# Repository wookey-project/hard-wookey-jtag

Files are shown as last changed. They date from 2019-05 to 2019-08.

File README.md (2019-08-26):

# WooKey JTAG Flasher PCB

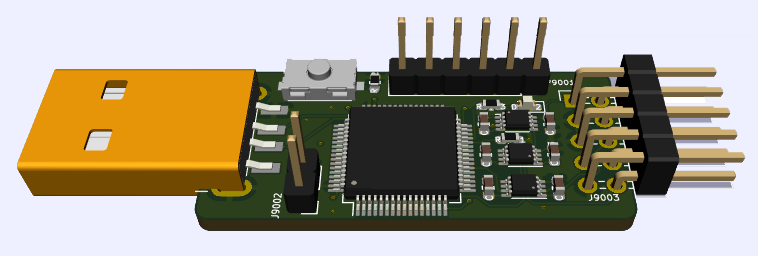
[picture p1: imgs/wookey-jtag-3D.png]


## Introduction

Wookey | https://wookey-project.github.io/
Copyright 2018 ANSSI

Authors: The Wookey project Team <wookey@ssi.gouv.fr>

The Wookey from [ANSSI](https://www.ssi.gouv.fr) is an open source
hardware design, implementing an Encrypted Flash Drives.

This repository is aimed towards developers.

### Revision information

This directory contains the hardware design for the Wookey board, first public version (Wookey V2).

### PCB editing tools

All PCB files (schematic and PCB layout) have been designed using the KiCad EDA.
This Cross Platform and Open Source Electronics Design Automation Suite can be downloaded
on http://kicad-pcb.org/.

## Production files generation 101

### Configure the project

KiCad binaries location may change regarding your operating system.
This is why you have to set your environment.
This is done by sourcing the `setenv.sh` script. This script exports
all paths that are required in order to automaticaly generate the production files.

Most of the time, the paths proposed in this script are not the one you use in your specific installation.
The `setenv.sh` script support easy variables overloading by including a `setenv.local.sh` script file if this file exists in the same directory.
If you need to overload some of the variables of the `setenv.sh` script, just add them to your own `setenv.local.sh` file.
Here is an example to define KiCad environement path on Apple Mac OS.

```
  $ echo "export PYTHON_BIN_PATH = /Applications/KiCad/kicad.app/Contents/Frameworks/Python.framework/Versions/2.7/bin/python" > setenv.local.sh
  $ source setenv.sh
  Loading local SDK settings...
  =========================================================
  === Kicad environment configuration
  =========================================================
  PYTHON_BIN_PATH   = /Applications/KiCad/kicad.app/Contents/Frameworks/Python.framework/Versions/2.7/bin/python
  PYTHON_PATH     = /Applications/Kicad/kicad.app/Contents/Frameworks/python/site-packages
  BOM_GEN_PATH = /Applications/Kicad/kicad.app/Contents/SharedSupport/plugins/bom2grouped_csv.xsl
  TOOLS_PATH = ../../../tools
  =========================================================
```

The production files can be generated using the following command.

```
$ make
```

This will generate the production files in a new sub directory.
The directory name may differ according the project your are working with.

## PCB Pinout

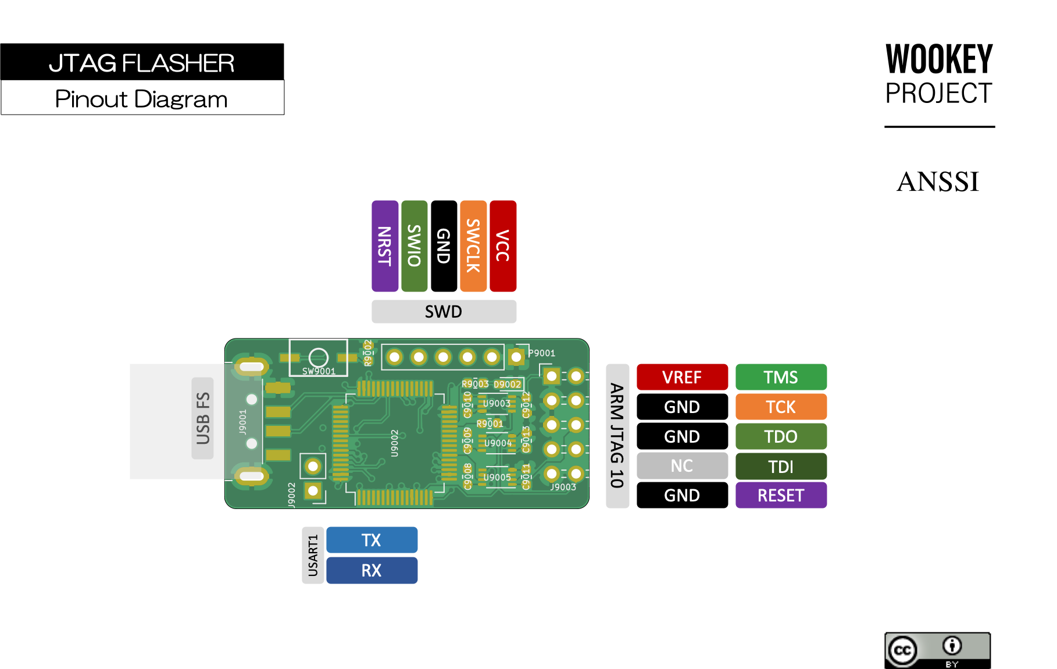
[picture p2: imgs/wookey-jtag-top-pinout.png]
Pinout


## PCB Layers

### PCB TOP layer

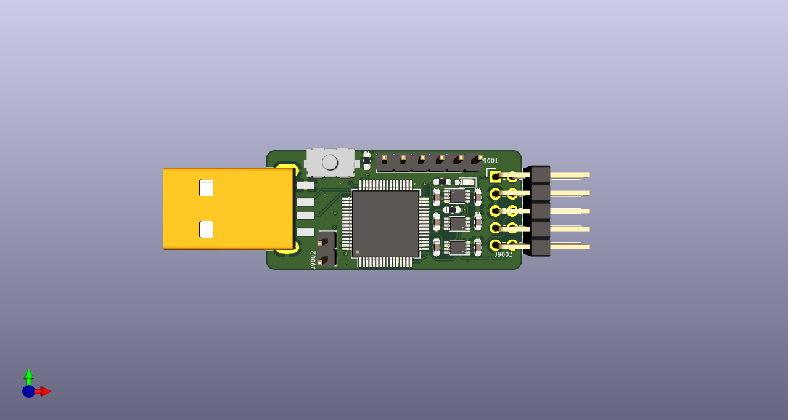
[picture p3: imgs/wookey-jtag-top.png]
TOP


### PCB BOTTOM layer

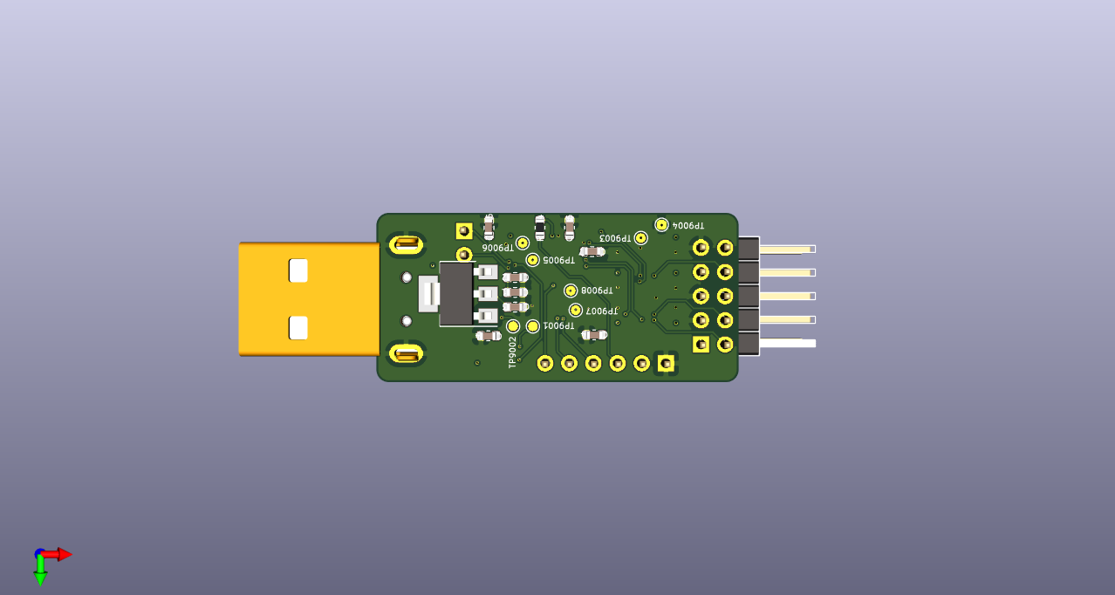
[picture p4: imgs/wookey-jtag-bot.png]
BOT


### Layers

Order and type of copper layers:
  TOP:  signal, front components
  GND:  ground plane
  PWR:  ground and power plane
  BOT:  signal, back components

### Stackup
4 layers, 1.6mm thickness
Outer layers 1 oz base copper foil
Inner layers 0.5 oz base copper foil

Electroless Nickel Immersion Gold (ENIG) surface finish

solder resist   0.0254mm
copper          0.0356mm    L1 (TOP)
FR408 prepreg   0.1702mm
copper          0.0178mm    L2 (GND)
FR408           1.1938mm
copper          0.0178mm    L3 (PWR)
FR408 prepreg   0.1702mm
copper          0.0356mm    L4 (BOT)
solder resist   0.0254mm

The substrate for both the core and prepreg is FR408,
with a dielectric constant of 3.66 at 1GHz.
The prepreg is comprised of 2 layers of Isola 2113.

## Regulatory compliance & handling

The Wookey board is intended for use as a development platform for hardware
or software. The board is an open system design, which does not include a
shielded enclosure. This may cause interference to other electrical or
electronic devices in close proximity. In a domestic environment, this product
may cause radio interference in which case the user may be required to take
adequate measures. In addition, this board should not be used near any medical
equipment or RF devices.

The board is sensitive to ESD. Hold the board only by its edges. After removing
the board from its box, place it on a grounded, static-free surface.

The board can become hot, like any fan-less design, during continuous high CPU
loads, mind its temperature while handling it.

## License

Wookey | https://wookey-project.github.io/
Copyright 2018 ANSSI

Authors: The Wookey project Team <wookey@ssi.gouv.fr>

This is an open hardware design licensed under the terms of the CERN Open
Hardware Licence (OHL) v1.2.

You may redistribute and modify this documentation under the terms of the CERN
OHL v.1.2 (http://ohwr.org/cernohl). This documentation is distributed WITHOUT
ANY EXPRESS OR IMPLIED WARRANTY, INCLUDING OF MERCHANTABILITY, SATISFACTORY
QUALITY AND FITNESS FOR A PARTICULAR PURPOSE. Please see the CERN OHL v.1.2 for
applicable conditions.

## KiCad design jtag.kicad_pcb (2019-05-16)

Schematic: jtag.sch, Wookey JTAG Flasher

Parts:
C9001, C9003: 10uF; C_0603_1608Metric; MFG Part Num TP8M106M6R3C
C9002, C9004, C9005, C9006, C9007, C9008, C9009, C9010, C9011, C9012, C9013, C9014: 100nF; C_0603_1608Metric; MFG Part Num GRM188R71H104KA93D
D9002: LED BLUE; LED_0603_1608Metric_Castellated; MFG Part Num VLMB1300-GS08
J9001: USB; USB_A_CNCTech_1001-011-01101_Horizontal
J9002: Conn_01x03; PinHeader_1x02_P2.54mm_Vertical
J9003: JTAG; PinHeader_2x05_P2.54mm_Horizontal
P9001: DEBUG/PROG; PinHeader_1x06_P2.54mm_Vertical; MFG Part Num 90120-0766
R9001, R9002, R9004: 10K; R_0603_1608Metric
R9003: 470; R_0603_1608Metric
SW9001: DFU; KSR_TACTILE_SWITCH; MFG Part Num KSR231G LFS
TP9001: MSWDIO; TestPoint_Pad_D1.0mm
TP9002: MSWCLK; TestPoint_Pad_D1.0mm
TP9003: +3V3; TestPoint_Pad_D1.0mm
TP9004: GND; TestPoint_Pad_D1.0mm
TP9005: CAN1_RX; TestPoint_Pad_D1.0mm
TP9006: CAN1_TX; TestPoint_Pad_D1.0mm
TP9007: CAN2_RX; TestPoint_Pad_D1.0mm
TP9008: CAN2_TX; TestPoint_Pad_D1.0mm
U9001: LD1117S33TR; SOT-223; MFG Part Num LD1117S33TR
U9002: STM32F105RBTx; LQFP-64_10x10mm_P0.5mm
U9003, U9004, U9005: 74LVCH2T45DC; VSSOP-8_2.3x2mm_P0.5mm

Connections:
+3V3: C9003.1, C9004.1, C9005.1, C9006.1, C9007.1, C9008.1, C9009.1, C9010.1, C9014.1, P9001.2, R9004.1, SW9001.1, TP9003.1, U9001.2 (VO), U9002.1 (VBAT), U9002.13 (VDDA), U9002.19 (VDD), U9002.32 (VDD), U9002.48 (VDD), U9002.64 (VDD), U9003.1 (VCCA), U9004.8 (VCCB), U9005.8 (VCCB)
+5V: C9001.1, C9002.1, J9001.1 (VBUS), U9001.3 (VI), U9002.42 (PA9)
/BOOT0: R9002.1, SW9001.2, U9002.60 (BOOT0)
/BOOT1: R9001.1, U9002.28 (PB2)
/CAN1_RX: TP9005.1, U9002.61 (PB8)
/CAN1_TX: TP9006.1, U9002.62 (PB9)
/CAN2_RX: TP9007.1, U9002.33 (PB12)
/CAN2_TX: TP9008.1, U9002.34 (PB13)
/JTAG_DIR: U9002.15 (PA1), U9003.5 (DIR), U9004.5 (DIR), U9005.5 (DIR)
/JTAG_NRESET: U9002.16 (PA2), U9004.6 (2B)
/JTAG_OUT_TCK: J9003.4 (SWDCLK/TCK), U9003.6 (2B)
/JTAG_OUT_TDI: J9003.8 (NC/TDI), U9004.2 (1A)
/JTAG_OUT_TDO: J9003.6 (SWO/TDO), U9005.2 (1A)
/JTAG_OUT_TMS: J9003.2 (SWDIO/TMS), U9003.7 (1B)
/JTAG_OUT_TRESET: J9003.10 (~RESET~), U9004.3 (2A)
/JTAG_TCK: U9002.21 (PA5), U9003.3 (2A)
/JTAG_TDI: U9002.17 (PA3), U9004.7 (1B)
/JTAG_TDO: U9002.22 (PA6), U9005.7 (1B)
/JTAG_TMS: U9002.20 (PA4), U9003.2 (1A)
/JTAG_VREF: C9011.1, C9012.1, C9013.1, J9003.1 (VCC), U9003.8 (VCCB), U9004.1 (VCCA), U9005.1 (VCCA)
/LED1: R9003.1, U9002.29 (PB10)
/MCU_SWCLK: TP9002.1, U9002.49 (PA14)
/MCU_SWDIO: TP9001.1, U9002.46 (PA13)
/NRST: P9001.3, R9004.2, U9002.7 (NRST)
/RX: J9002.1, U9002.59 (PB7)
/SWCLK: P9001.4, U9002.38 (PC7)
/SWDIO: P9001.5, U9002.39 (PC8)
/SWO: P9001.6, U9002.55 (PB3)
/TX: J9002.2, U9002.58 (PB6)
/USB_FS_D+: J9001.3 (D+), U9002.45 (PA12)
/USB_FS_D-: J9001.2 (D-), U9002.44 (PA11)
GND: C9001.2, C9002.2, C9003.2, C9004.2, C9005.2, C9006.2, C9007.2, C9008.2, C9009.2, C9010.2, C9011.2, C9012.2, C9013.2, C9014.2, D9002.1 (K), J9001.4 (GND), J9001.5 (Shield), J9003.3 (GND), J9003.5 (GND), J9003.9 (GNDDetect), P9001.1, R9001.2, R9002.2, TP9004.1, U9001.1 (GND), U9002.12 (VSSA), U9002.18 (VSS), U9002.31 (VSS), U9002.47 (VSS), U9002.63 (VSS), U9003.4 (GND), U9004.4 (GND), U9005.4 (GND), U9005.6 (2B)
unnamed: D9002.2 (A), R9003.2

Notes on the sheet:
BOOT MODE
LED
POWER
Boot0 (1-2) = 0 => Flash memory aliased at 0x0000000

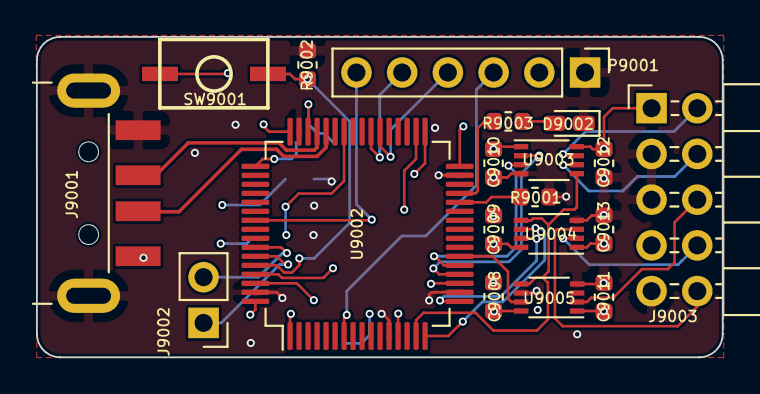
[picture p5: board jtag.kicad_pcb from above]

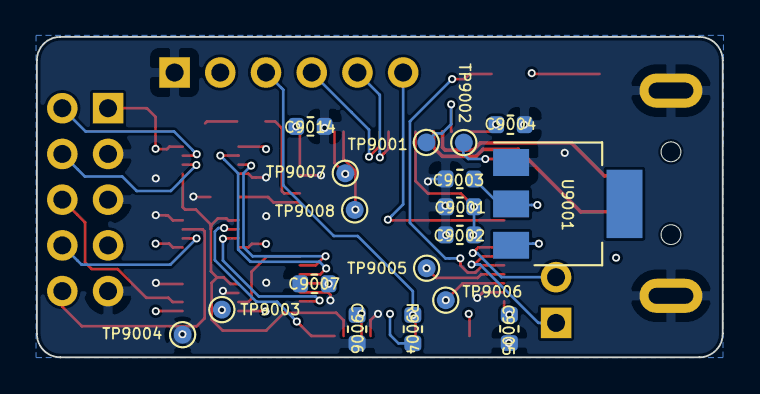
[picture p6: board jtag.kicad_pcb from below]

Board: 4 copper layers, 38.1 x 17.8 mm, 37 parts (18 on the bottom side), 33 nets.

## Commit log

2019-05-15 First import
    [jtag.kicad_pcb, jtag.sch]
2019-05-16 [enhancement] global cleanup
    [jtag.kicad_pcb]
2019-05-16 [enhancement] add pcb screenshots
2019-05-16 [enhancement] move pcb screenshots to imgs directory
    [jtag.kicad_pcb]
2019-05-16 [enhancement] Reference LICENSE in files
    [jtag.kicad_pcb, jtag.sch]
2019-05-16 [enhancement] General cleanup
    [jtag.kicad_pcb]

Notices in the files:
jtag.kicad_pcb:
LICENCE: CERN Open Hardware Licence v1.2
